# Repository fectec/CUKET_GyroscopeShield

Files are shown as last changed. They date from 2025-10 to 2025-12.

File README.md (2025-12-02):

# MO-2 Gyroscope Verification Shield

<p align="justify">
The PCB is designed as a shield for the NUCLEO-F446RET6, mechanically capable of stacking directly on top of the development board. This configuration routes all power and communication signals from the microcontroller to the peripheral components without the need for external jumper wires.
</p>

<p align="center">
  Front Unsoldered
  Back Unsoldered
  <br>
  Soldered Standalone
  Soldered with Nucleo
  <br>
  <em>Figure 1: PCB manufacturing and integration stages.</em>
</p>

<p align="center">
  View 1
  View 2
  <br>
  View 3
  View 4
  <br>
  <em>Figure 2: Lateral profiles of the soldered system.</em>
</p>

<p align="justify">
The communication architecture relies on two distinct protocols: I<sup>2</sup>C for the Pmod gyroscope interface and SPI for the flash memory. Table 1 details the point-to-point wiring between the Pmod J2 connector and the NUCLEO headers.
</p>

| Pmod Pin | Function | NUCLEO Pin |
| :--- | :--- | :--- |
| J2 Pin 5 | SCL | PB8 (I2C1_SCL) |
| J2 Pin 6 | SDA | PB9 (I2C1_SDA) |
| J2 Pin 7 | GND | GND |
| J2 Pin 8 | VCC | +3V3 |
<p align="justify"><em>Table 1: Pin mapping between Pmod Gyroscope (L3G4200D) and NUCLEO-F446RE.</em></p>

<p align="justify">
For the data logging subsystem, due to the complexity of the memory circuit, Table 2 lists only the utilized microcontroller pins. For complete electrical connections, refer to the schematic diagram in Figure 3.
</p>

| NUCLEO Pin (Function) |
| :--- |
| PB14 (SPI2_MISO) |
| PB15 (SPI2_MOSI) |
| PC7 (SPI2_SCLK) |
| PA4 (Chip Select) |
| GND |
| +3V3 (Flash Memory Power Supply) |
<p align="justify"><em>Table 2: NUCLEO-F446RE Pin assignment for SPI Flash Memory interface.</em></p>

<p align="justify">
The power subsystem is designed around an LM2596 step-down switching regulator. This component regulates the input voltage from a main battery pack—comprising two Lithium-Ion cells—to a stable 5V output required to power the NUCLEO board.
</p>

<p align="justify">
Additionally, the PCB integrates essential user interface components for operational control: a mechanical toggle switch for main power isolation, a status LED to provide visual feedback during algorithm execution, and a push-button connected via a long cable. The button serves as a manual logic input, facilitating control over the state of the system during the thermal chamber test setup.
</p>

<p align="center">
  Electrical Schematic
  <br>
  <em>Figure 3: Electrical Schematic of the MO-2 Gyroscope Verification Shield.</em>
</p>

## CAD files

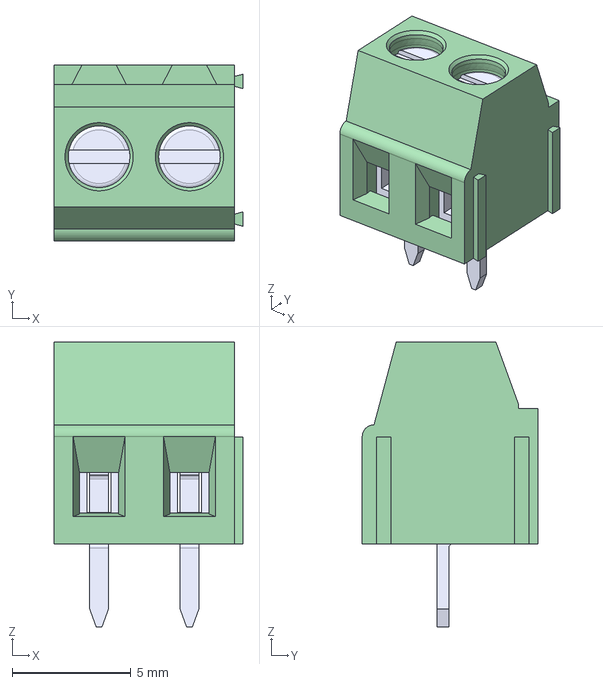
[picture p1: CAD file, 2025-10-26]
GYRO_PCB/COMPONENTS/3D/TerminalBlock.step
7.97 x 7.40 x 12.0 mm

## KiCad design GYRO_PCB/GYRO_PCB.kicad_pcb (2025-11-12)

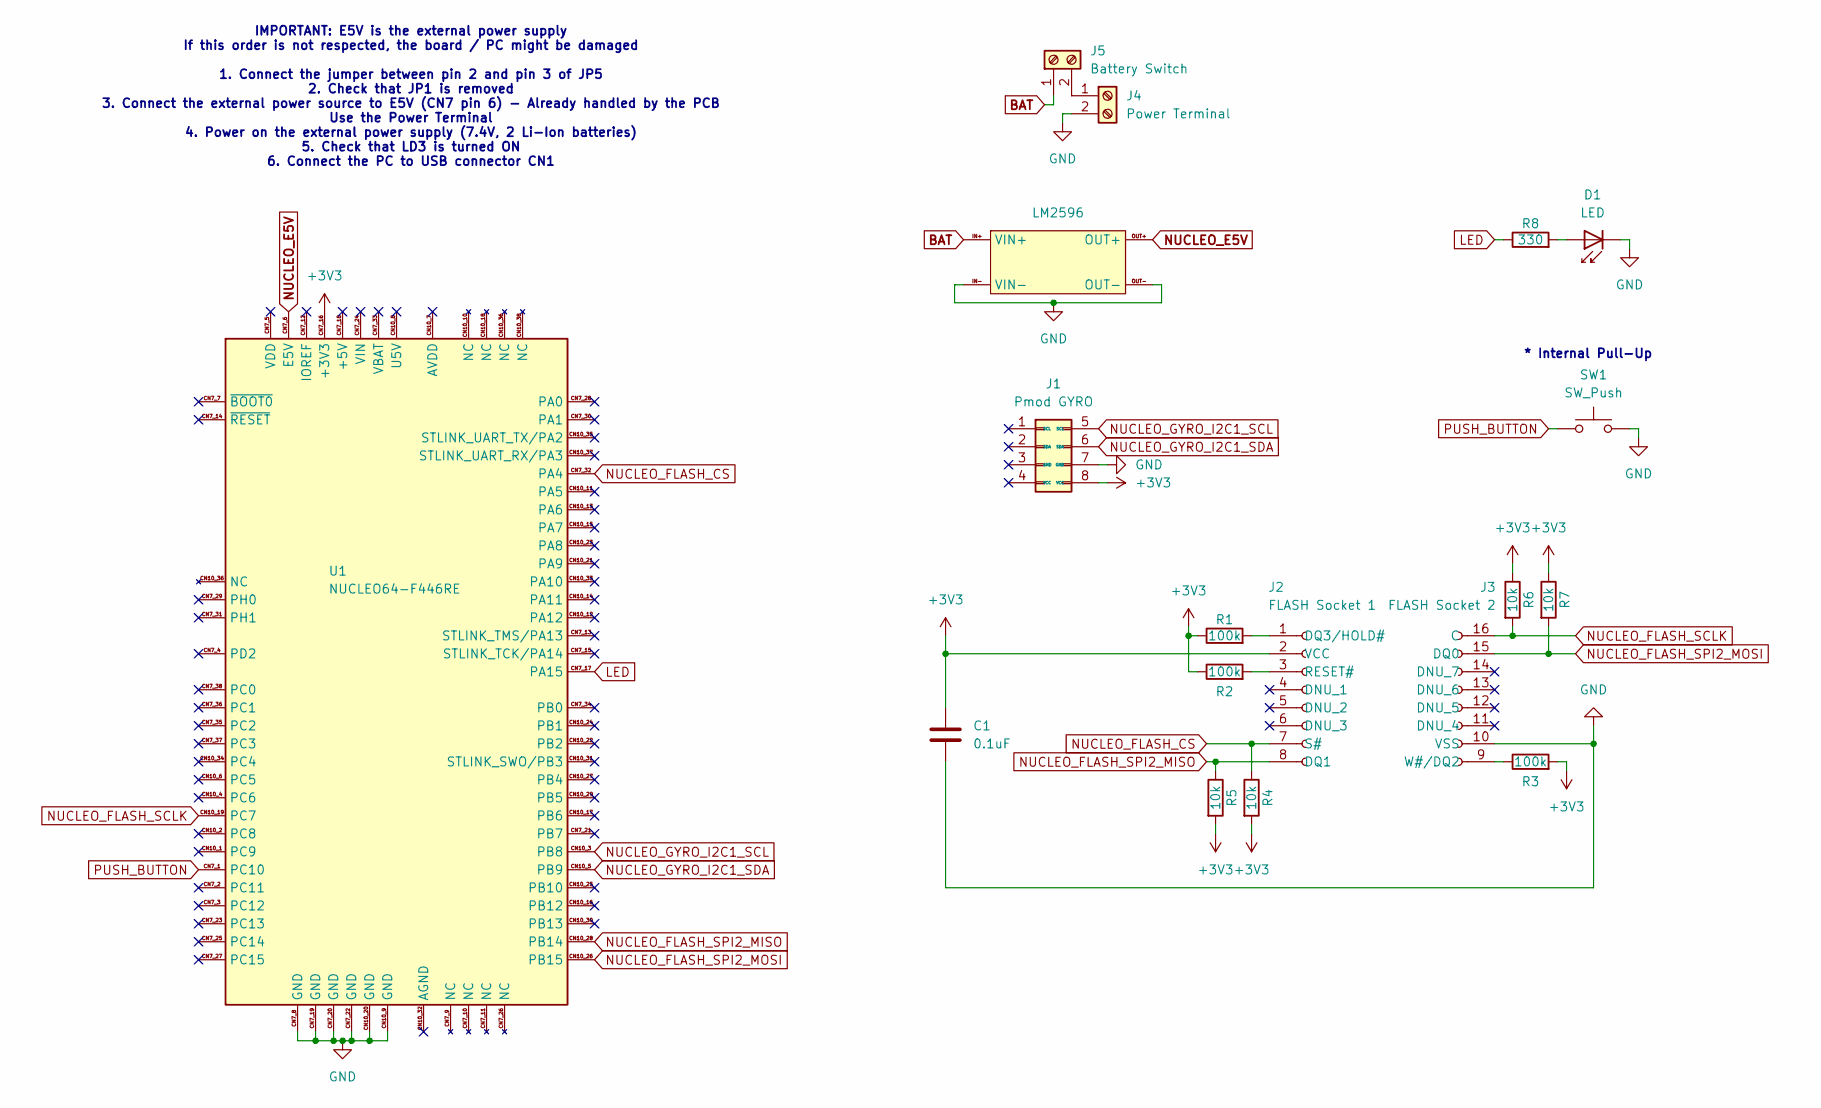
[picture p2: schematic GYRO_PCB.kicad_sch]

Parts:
C1: 0.1uF; C_Disc_D8.0mm_W2.5mm_P5.00mm
D1: LED; LED_D5.0mm_IRBlack
J1: Pmod GYRO; PinSocket_2x04_P2.54mm_Vertical_Custom
J2: FLASH Socket 1; PinSocket_1x08_P2.54mm_Vertical
J3: FLASH Socket 2; PinSocket_1x08_P2.54mm_Vertical_Custom
J4: Power Terminal; TerminalBlock_MaiXu_MX126-5.0-02P_1x02_P5.00mm
J5: Battery Switch; TerminalBlock_MaiXu_MX126-5.0-02P_1x02_P5.00mm
LM2596: LM2596 Module
R1, R2, R3: 100k; R_Axial_DIN0207_L6.3mm_D2.5mm_P10.16mm_Horizontal
R4, R5, R6, R7: 10k; R_Axial_DIN0207_L6.3mm_D2.5mm_P10.16mm_Horizontal
R8: 330; R_Axial_DIN0207_L6.3mm_D2.5mm_P10.16mm_Horizontal
SW1: SW_Push; PinSocket_1x02_P2.54mm_Vertical
U1: NUCLEO64-F446RE; NUCLEO-F446RE

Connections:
+3V3: C1.1, J1.8 (VCC), J2.2 (VCC), R1.1, R2.1, R3.2, R4.2, R5.2, R6.1, R7.1, U1.CN7_16 (+3V3)
BAT: J5.1, LM2596.IN+ (VIN+)
GND: C1.2, D1.1 (K), J1.7 (GND), J3.10 (VSS), J4.2, LM2596.IN- (VIN-), LM2596.OUT-, SW1.2, U1.CN7_8 (GND), U1.CN7_19 (GND), U1.CN7_20 (GND), U1.CN7_22 (GND), U1.CN10_9 (GND), U1.CN10_20 (GND)
LED: R8.1, U1.CN7_17 (PA15)
NUCLEO_E5V: LM2596.OUT+, U1.CN7_6 (E5V)
NUCLEO_FLASH_CS: J2.7 (S#), R4.1, U1.CN7_32 (PA4)
NUCLEO_FLASH_SCLK: J3.16 (C), R6.2, U1.CN10_19 (PC7)
NUCLEO_FLASH_SPI2_MISO: J2.8 (DQ1), R5.1, U1.CN10_28 (PB14)
NUCLEO_FLASH_SPI2_MOSI: J3.15 (DQ0), R7.2, U1.CN10_26 (PB15)
NUCLEO_GYRO_I2C1_SCL: J1.5 (SCL), U1.CN10_3 (PB8)
NUCLEO_GYRO_I2C1_SDA: J1.6 (SDA), U1.CN10_5 (PB9)
unnamed: D1.2 (A), R8.2
unnamed: J2.1 (DQ3/HOLD#), R1.2
unnamed: J2.3 (RESET#), R2.2
unnamed: J3.9 (W#/DQ2), R3.1
unnamed: J4.1, J5.2
PUSH_BUTTON: SW1.1, U1.CN7_1 (PC10)

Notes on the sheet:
IMPORTANT: E5V is the external power supply If this order is not respected, the board / PC might be damaged 1. Connect the jumper between pin 2 and pin 3 of JP5 2. Check that JP1 is removed 3. Connect the external power source to E5V (CN7 pin 6) - Already handled by the PCB Use the Power Terminal 4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
* Internal Pull-Up

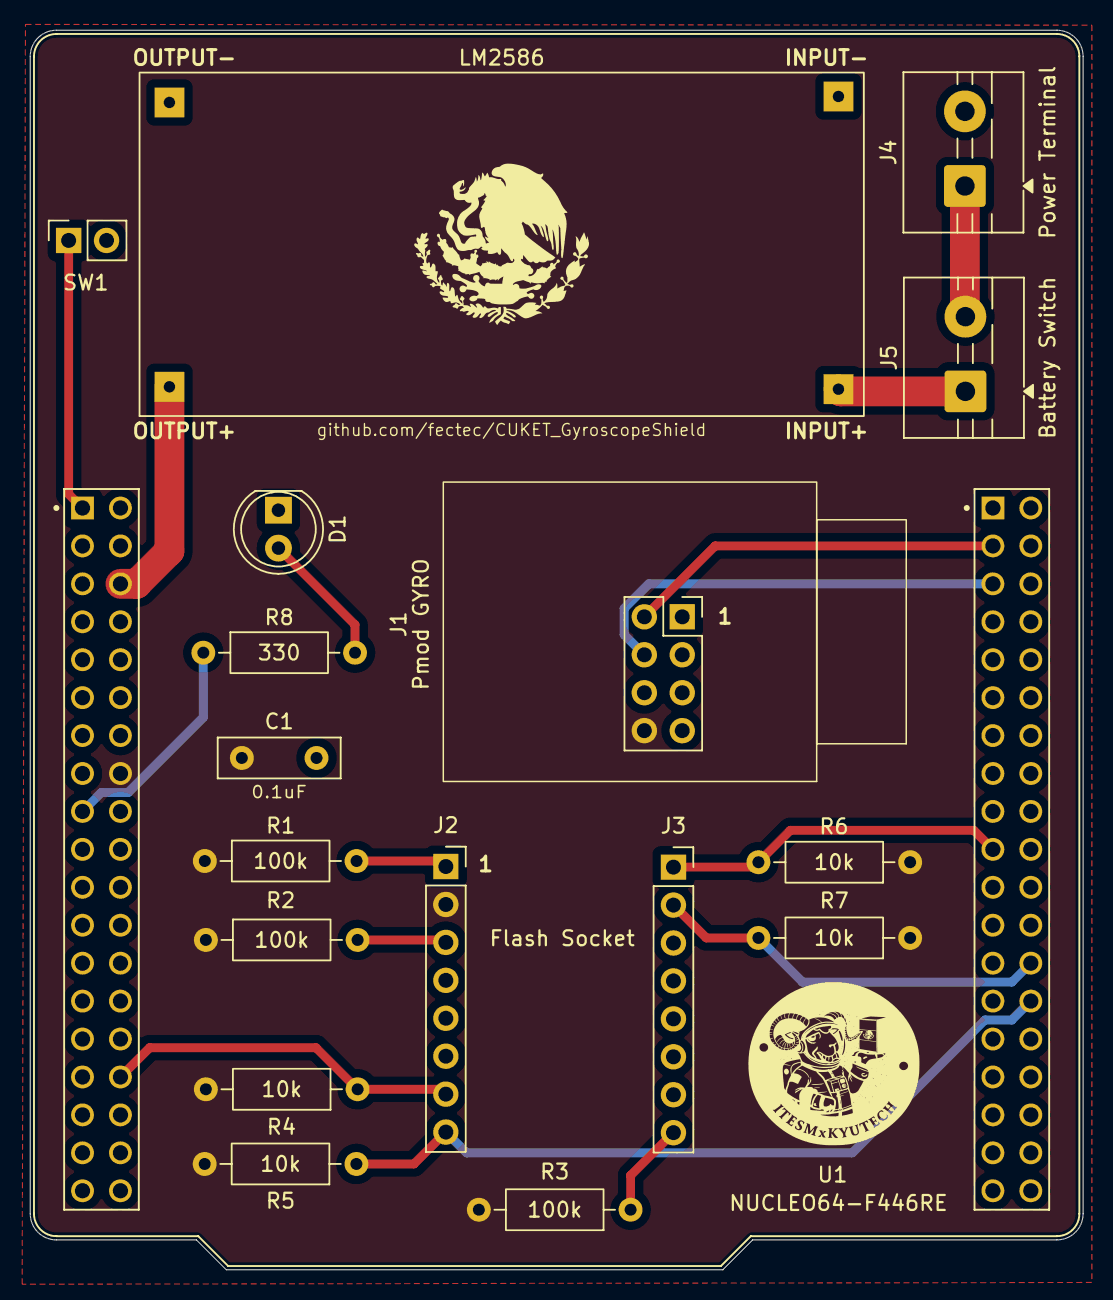
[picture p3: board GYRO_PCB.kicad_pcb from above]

Board: 2 copper layers, 70.5 x 83.0 mm, 18 parts (0 on the bottom side), 17 nets.

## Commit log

2025-10-23 feat: add footprint + symbol + 3D model for NUCCLEO-F446RE
2025-10-23 feat: add kicad project
    [GYRO_PCB.kicad_pcb, GYRO_PCB.kicad_sch]
2025-10-23 feat: add symbols and footprints for principal components
    [GYRO_PCB.kicad_sch]
2025-10-23 feat: most of schematic done
    [GYRO_PCB.kicad_pcb, GYRO_PCB.kicad_sch]
2025-10-23 feat: finish PCB draft
    [GYRO_PCB.kicad_pcb, GYRO_PCB.kicad_sch]
2025-10-23 feat: add NUCLEO 3D model
    [GYRO_PCB.kicad_pcb]
2025-10-24 New schematic
    [GYRO_PCB.kicad_pcb, GYRO_PCB.kicad_sch, UA7805CKCS.step]
2025-10-24 new pcb and schematic
    [GYRO_PCB.kicad_pcb, GYRO_PCB.kicad_sch]
2025-10-25 updated footprint for LED
    [GYRO_PCB.kicad_pcb, GYRO_PCB.kicad_sch]
2025-10-26 refactor: clean schematic & PCB + feat: add LM2596 & terminal 3D models
    [GYRO_PCB.kicad_pcb, GYRO_PCB.kicad_sch, TerminalBlock.step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]
2025-10-27 fabrication files
    [GYRO_PCB-B_Cu.gbr, GYRO_PCB-B_Mask.gbr, GYRO_PCB-B_Paste.gbr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]
2025-11-05 fix: correct DRC & add mechanical limits to gyroscope
    [GYRO_PCB-B_Cu.gbr, GYRO_PCB-B_Mask.gbr, GYRO_PCB-B_Paste.gbr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]
2025-11-05 feat: add flash socket height
    [GYRO_PCB.kicad_pcb]
2025-11-12 feat: add push button
    [GYRO_PCB.kicad_pcb, GYRO_PCB.kicad_sch]
2025-11-12 feat: routing done
    [GYRO_PCB.kicad_pcb]
2025-11-12 feat: add footprints
    [GYRO_PCB.kicad_pcb]
2025-11-12 fix: change logo
    [GYRO_PCB.kicad_pcb]
2025-11-12 fix: last revision complete - ready to order
    [GYRO_PCB.kicad_pcb]
